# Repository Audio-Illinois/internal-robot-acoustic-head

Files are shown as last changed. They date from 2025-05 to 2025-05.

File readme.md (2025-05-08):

# Robotic Dummy Heads for Acoustic Data Collection

This repository contains open-source resources for building and using **robot dummy heads**, developed to collect high-quality data for the study of audio and acoustic processing algorithms. These heads are designed to mimic human acoustic properties while being mountable on robotic platforms, supporting realistic audio data capture even in environments with source motion.

<div style="text-align:center">
Banner image showing 3D printed heads assembled in a row and disassembled in a suitcase. University/sponsor affilidations are shown at the bottom
</div>

## Overview
In tasks like sound localization, speech enhancement, or multi-microphone array processing, capturing realistic human-like audio is critical. Our dummy heads are designed to:

- Accurately model human head-related transfer functions (HRTFs)
- Provide interchangeable components for various research needs
- Integrate naturally with robotic platforms (e.g. our quiet turntable)

Our quiet turntable is designed to:
- Be inaudible in the far-field (>1.0 m), enabling recordings with source motion that are not possible with conventional, noisy robots
- Accurately repeat prior movements, enabling the use of objective performance metrics

Overall, these tools enable robust, reproducible audio data collection under controlled and in-the-wild conditions.

## Repository Structure

The project is modular, with each core component in its own subdirectory:

```
robot-dummy-head/
├── head-shell/ # 3D models and manufacturing specs for the head structure
├── robot-mount/ # The quiet turntable robot: 3D models, electronics, and code
└── auto-audio/ # Scripts for automated spatially-stationary and dynamic recordings with the head+robot
```

Further, detailed information can be found in each directory. `auto-audio` presumes that `head-shell` and `robot-mount` have been viewed and the instructions within followed, yielding the fully-assembled robotic head.

## Getting Started

Each subdirectory contains a README with build instructions, parts lists, and diagrams. To get started quickly:

1. Clone this repo
2. Review the [`head-shell`](./head-shell) to purchase and assemble the parts of the dummy head
3. Follow [`robot-mount`](./robot-mount) to purchase and assemble the parts of the robot turntable
4. Use [`auto-audio`](./auto-audio) to perform automatic audio recordings using the head + robot

## Applications

- Binaural spatial audio
- Objective evaluation of audio and acoustic processing algorithms
- Dataset collection for speech source separation and enhancement
- Dataset collection for sound source localization

## Citation

If you use this resource in your research, please cite the following. Various acousitic measurements validating the acoustic realism of the dummy head or quietness and repeatability of the robot are provided in the paper as well.

```
@misc{lu2025,
      title={Accelerating Audio Research with Robotic Dummy Heads}, 
      author={Austin Lu and Kanad Sarkar and Yongjie Zhuang and Leo Lin and Ryan M Corey and Andrew C Singer},
      year={2025},
      eprint={2505.04548},
      archivePrefix={arXiv},
      primaryClass={eess.AS},
      url={https://arxiv.org/abs/2505.04548}, 
}
```

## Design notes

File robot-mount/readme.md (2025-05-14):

# Quiet Rotating Platform

This turntable locks onto the 3D printed head and rotates it quietly, enabling audio experiments with _repeatable_ source motion.

## ⚙ 1. Sourcing the parts

#### 🖨 3D Print Files

All printable components are provided as `.stl` files in the [`solids/`](./solids) directory:

| Links | Description |
| --- | --- |
| [Base Platform](./solids/base.stl) <br/> + [Motor Case](./solids/motorcase.stl) | The main stationary part of the turntable that encases the motor and homing induction sensor |
| [Grabber](./solids/grabber.stl) <br/> + [Plate](./solids/plate.stl) | The payload portion of the turntable that friction-fits with a dummy head and is rotated by the motor |

#### 🧾 PCB Fabrication Files

All files required for manufacturing the PCB can be found in [`gerber.zip`](./gerber.zip). This can be uploaded to a PCB manufacturer such as [PCBWay](https://www.pcbway.com/) and fabricated with low turnaround time and cost. Tutorials on using PCBWay are available on YouTube.

#### 🔩 Purchased Parts

The following parts need to be soldered to the PCB.

| Part | Qty | Designation on Schematic | Link |
| --- | --- | --- | --- |
| Arduino Nano | 1 | None | [arduino](https://store.arduino.cc/products/arduino-nano) |
| TMC 2208 motor driver chip | 1 | None | [digikey](https://www.digikey.com/short/j84mhvfm)|
| Terminal Block for stepper motor | 1 | J2 (Screw_Terminal for motor) | [digikey](https://www.digikey.com/en/products/detail/phoenix-contact/1715747/260633) |
| Barrel Jack for power | 1 | J1 (Barrel_Jack) | [digikey](https://www.digikey.com/en/products/detail/same-sky-formerly-cui-devices/PJ-002A/96962) |
| PinSocket headers for Arduino Nano | 2 | J3, J5 | [digikey](https://www.digikey.com/en/products/detail/sullins-connector-solutions/PPTC151LFBN-RC/810153) |
| PinSocket headers for TMC 2208 driver chip | 2 | J4, J6 | [digikey](https://www.digikey.com/en/products/detail/w%C3%BCrth-elektronik/61300811821/17737805) |
| Induction sensor terminal block | 1 | J7 | [digikey](https://www.digikey.com/en/products/detail/phoenix-contact/1715734/260632) |
| Adafruit adjustable power supply  (Run it at 18 Volts) | 1 | None | [digikey](https://www.digikey.com/short/31r0mw15)  |
| Induction sensor | 1 | None | [amazon](https://www.amazon.com/Taiss-NO%EF%BC%88Normally-LJ12A3-4-Z-inductive-Proximity/dp/B073XD44CW) |

The following components are used in/on the 3D printed parts.

| Part | Qty | Link |
| --- | --- | --- |
| Small-size Stepper Motor | 1 | [digikey](https://www.digikey.com/en/products/detail/adafruit-industries-llc/324/5022791)|
| Flanged ball bearing | 1 | [mcmaster](https://www.mcmaster.com/57155K573/) |
| M3x20mm screws | 5 | [mcmaster](https://www.mcmaster.com/91292A123/) |
| M3x8mm screws | 20 | [mcmaster](https://www.mcmaster.com/91292A112/) |
| Variable power supply* | 1 | [digikey](https://www.digikey.com/en/products/detail/adafruit-industries-llc/5130/15277535) |

*We set the voltage to 20V.

## 🔧 2. Assembly Instructions

Follow the designators on this PCB to solder the parts above. Alternatively, consult the [schematic](./imgs/pcb_v2_schematic.png)

<div style="text-align:center">
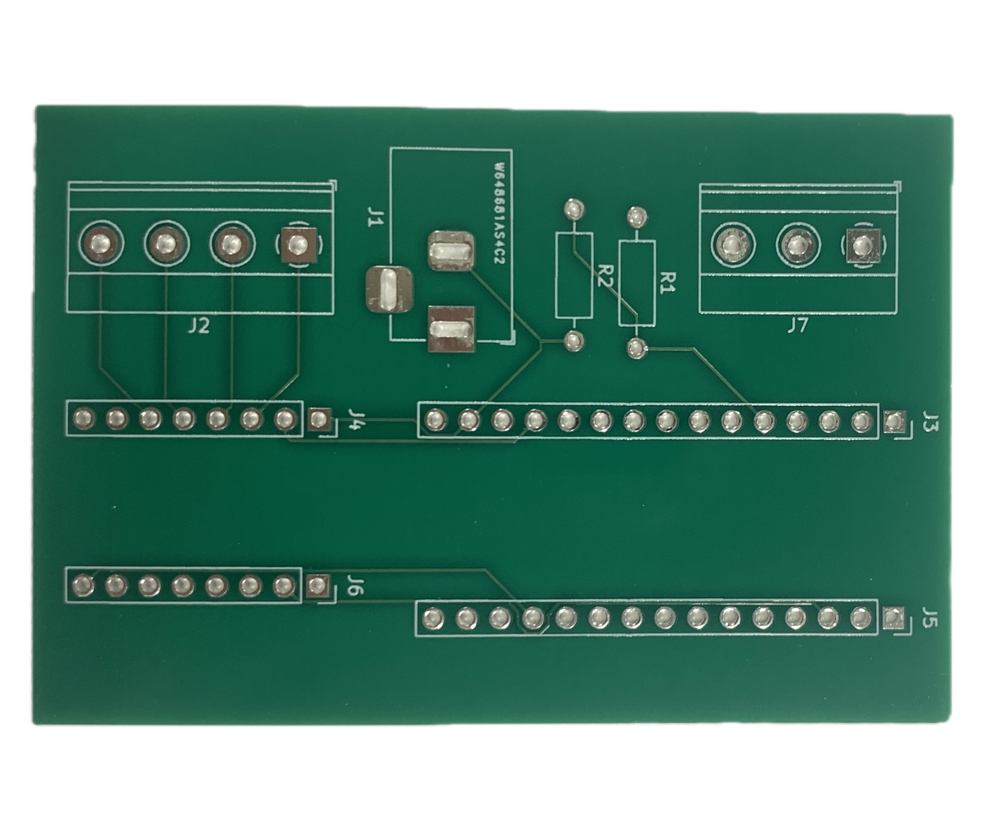
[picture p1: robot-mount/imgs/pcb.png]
Bare PCB

</div>

Final assembled PCB:

<div style="text-align:center">
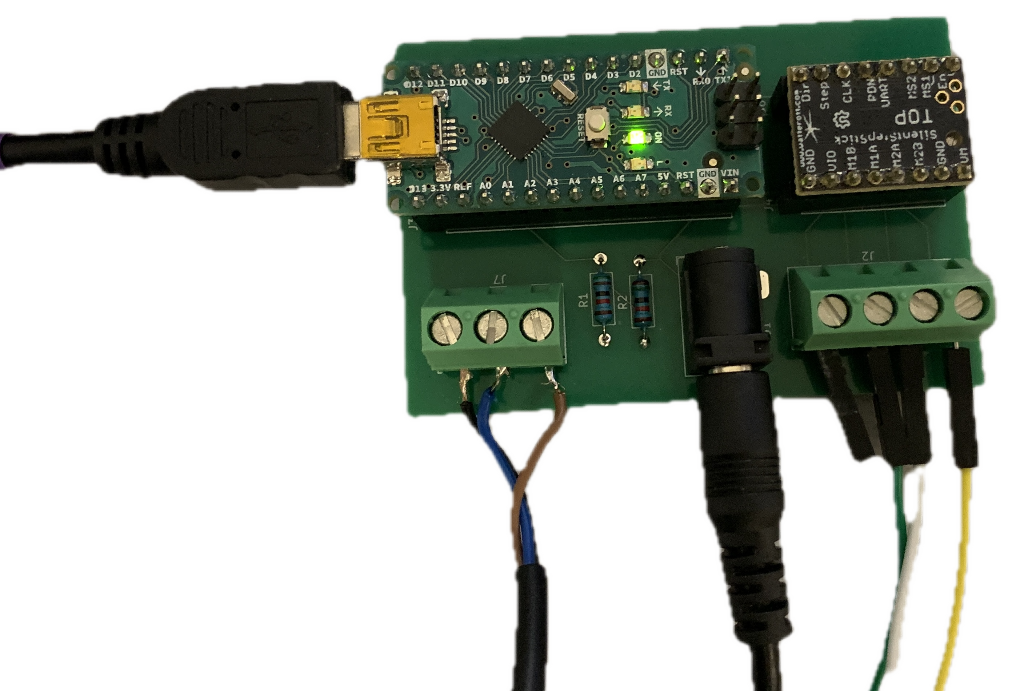
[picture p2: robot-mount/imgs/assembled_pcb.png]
Final Assembled PCB

</div>

The PCB can be connected to the motor as follows:
<div style="text-align:center">
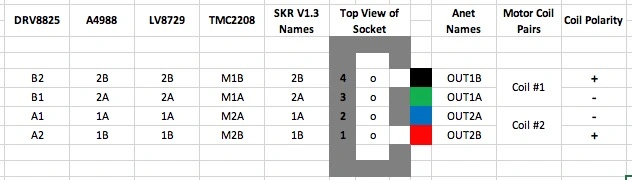
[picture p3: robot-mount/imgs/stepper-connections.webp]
Table of how to connect the motor to the driver

</div>

Follow [this](https://github.com/teemuatlut/TMC2208Stepper?tab=readme-ov-file) github tutorial to solder a UART bridge on the TMC motor driver.

Final assembled robot with dummy head:

<div style="text-align:center">
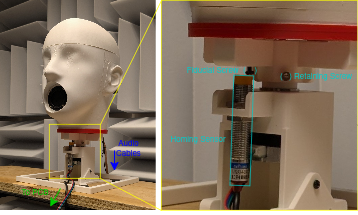
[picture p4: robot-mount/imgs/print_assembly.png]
Annotated photos of the dummy head atop the turntable. PCB excluded.

</div>

## 💾 3. Software

#### 1. Setup host PC

Clone the repository
```bash
git clone https://github.com/Audio-Illinois/robot-acoustic-head.git
cd robot-acoustic-head/robot-mount
```
Onto a PC with either ALSA (Linux) or ASIO (Windows) audio drivers. Preferably, have Python 3.8.10 installed.

Install the necessary libraries
```bash
python3 -m pip install -r ./requirements.txt
```

#### 2. Flash Arduino

Install [`arduino-cli`](https://docs.arduino.cc/arduino-cli/installation/) for convenient Arduino flashing. Then, run:
```bash
arduino-cli lib install tmc2208stepper # install needed library package

cd scripts
python3 ./upload.py -P $PORT
```
> 💡 On an Ubuntu machine, you likely should set `PORT=/dev/ttyUSB0`. On Windows, try `PORT=COM4`.

Errors are expected when first calling this script - just follow the suggestions provided.

This is optional and you can instead use the [Arduino IDE](https://www.arduino.cc/en/software/), which will also make identifying the relevant serial port easier.

In either case, ensure that the [TMC2208Stepper](https://docs.arduino.cc/libraries/tmc2208stepper/) library is installed via Package Manager.

#### 3. Control the robot through console commands

Run 
```bash
python3 ./teleop.py $PORT
```

Example commands are `home`, which can be used to check that the homing induction sensor is wired properly, and `move <degrees>`/`move <degrees> <revs/s>` which is used to check that the motor calibration is correct. 

> 💡 It is advised to clamp the robot turntable onto a desk or other heavy platform.

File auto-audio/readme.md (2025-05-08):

# Automated Experiments with the Robot Dummy Head

Presuming you have both the dummy head in [`../head-shell/`](../head-shell/) and robot turntable in [`../robot-mount/`](../robot-mount/) set up an assembled properly, with teleop working for the latter, then you can run some basic automated experments using the scripts in this folder.

## 1. Setup

Connect the host PC to:
1. The robot PCB, via USB serial
2. Any audio interface

Ensure that the audio interface can be identified via Python. Note that the `sounddevice` library uses `PortAudio` to this end.

```python
import sounddevice as sd
sd.query_devices()
```

> 💡 A common issue is your device being listed, but with 0 input or output channels. Check that no other application is using the audio interface, or on Ubuntu, run `pulseaudio -k` to reset system audio.

Check robot responsiveness by following the guide in [`../robot-mount/`](../robot-mount/). Keep an eye out for egregious latency between submitting a command and the robot performing that action, or for mismatch between the commanded motion extent and the observed movement.

> 💡 On an Ubuntu machine, you likely should set `PORT=/dev/ttyUSB0`. On Windows, try `PORT=COM4`.

## 2. Automatic HRTF or Directivity recordings

Run
```bash
python3 ./auto_still.py -p $PORT -r $path_to_wav_to_play -w $path_to_save_recordings_to
```
to have the dummy head rotated in a full 360 degrees, in increments of 45 degrees. At each position, audio at `$path_to_wav_to_play` is played from the mouth loudspeaker (or whichever loudspeakers are connected to the audio interface). At the same time, audio is recorded from both ears (or whichever mics are connected to the audio interface) to `$path_to_save_recordings_to`. Before recording, the dummy head will self-home.

To measure an HRTF, instead of the mouth loudspeaker, a studio monitor in the far-field could be used as the audio output.
```bash
python3 ./auto_still.py -p $PORT -r $path_to_wav_to_play -w $path_to_save_recordings_to -i 15
```

To mesaure directivity of the dummy head, record from a single microphone in the far-field.
```bash
python3 ./auto_still.py -p $PORT -r $path_to_wav_to_play -w $path_to_save_recordings_to -i 15 -c 1
```

For convenience, we provide a [clip of a reading of the Rainbow Passage](https://www.voxforge.org/home/audacity/the-rainbow-passage) at `./audio/rp-01.wav`. 

## 3. Recording a moving sound source

Run
```bash
python3 ./auto_move.py -p $PORT -r $path_to_wav_to_play -w $path_to_save_recordings_to
```
to have the dummy head rotate _while_ audio is played and recorded. Before recording, the dummy head will self-home.

> 💡 A possible issue is latency in the recorded audio. This can be remedied with a loopback audio channel and subsequent sample-wise synchronization in post-processing.

> 💡 The above scripts were tested on an host PC with Ubuntu 20.04 LTS, ALSA audio, and Python 3.8.10, connected to a [Behringer U-Phoria UMC202HD](https://www.behringer.com/product.html?modelCode=0805-AAR) audio interface.

> 💡 Due to the choice of a weak-as-possible stepper motor, any tangles in the dummy head cables will **not** cause the dummy head to fall, or the cables to be damaged.

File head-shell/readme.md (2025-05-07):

# 3D Printed Dummy Head

When equipped with microphones in the faux ear canals, this dummy head can record realistic binaural audio. Using a loudspeaker at the mouth position, it may also produce humanlike speech, with appropriate directivity.

The parts are interlocking so that the design is fully 3D printed. Small screws can be used for stronger assembly, but this is optional.

<div style="text-align:center">
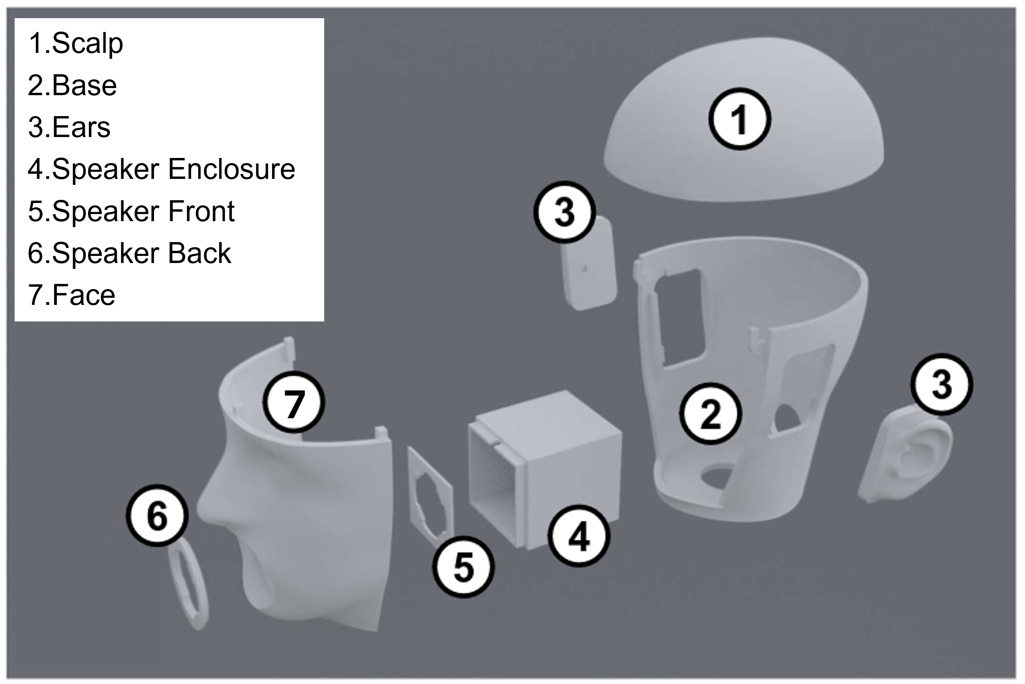
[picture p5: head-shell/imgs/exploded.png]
Exploded view of head parts

</div>

## Sourcing the Parts

#### 🖨 3D Print Files

All printable components are provided as `.stl` files in the [`solids/`](./solids) directory:

| Links | Features | Approx. Print Time* | Approx. Filament Usage** |
| --- | --- | --- | --- |
| [Left Ear](./solids/ear_left.stl) <br/> + [Right Ear](./solids/ear_right.stl) | Faux ear canals <br/> Realistic shape for binaural recordings | 3 hours (per) | 7 m (per) |
| [Base](./solids/main_base_repair.stl) <br/>+ [Face](./solids/main_face.stl) <br/>+ [Scalp](./solids/main_scalp_repair.stl) | Realistic proportions and ear-to-ear distance <br/> Port for microphone/loudspeaker cables | 18 hours (per) | 75±5 m (per)
| [Mouth Loudspeaker Enclosure](./solids/speaker_box.stl) <br/>+ [Front mounting plate](./solids/speaker_mount_front.stl) <br/>+ [Backplate](./solids/speaker_mount_back.stl) | Realistic talker directivity | 5 hours (total) | 25 m (total) |

*Based on a [Creality 3D Ender-5 Plus](https://www.creality.com/products/ender-5-plus-3d-printer) 3D Printer. The extra bed size of this printer is not actually necessary to print the head parts. We recommend using a [Bambu Lab X1 Carbon](https://us.store.bambulab.com/products/x1-carbon) for 3-4x faster print times.

**The full dummy head can be printed from a single [1 kg spool of 1.75mm PLA filament](https://www.hatchbox3d.com/collections/pla-1-75mm).

To print the parts:

1. **Open the `.stl` files** using a slicer program like [Bambu Studio](https://bambulab.com/en/software/studio) (we use this), [PrusaSlicer](https://www.prusa3d.com/prusaslicer/), or [Cura](https://ultimaker.com/software/ultimaker-cura).
   - Move the models so they don't intersect/overlap
   - Use the Auto-Orient tool to snap the models to the print bed, in an orientation that will reduce print time and support material usage
2. **Configure printer settings**.
   - Material: PLA (recommended)
   - Layer height: 0.2 mm (default)
   - Infill: 15% (default)
   - Supports: Type=normal(auto), Style=Snug
3. **Slice and export** the G-code.
   - The estimated print times and filament usage should roughly align with the above listed
4. **Print** the part using your 3D printer.

Need help getting started? Check out:
- [Beginner’s Guide to 3D Printing by All3DP](https://all3dp.com/2/how-to-3d-print-beginners-guide/)
- [Bambu Lab's Quick Start Guide](https://wiki.bambulab.com/en/x1/quick-start-guide)

#### 🔩 Purchased Parts
| Links | Qty | Features |
| --- | --- | --- |
| [Countryman B3 Omnidirectional Lavalier](https://countryman.com/product/b3-omnidirectional-lavalier/) | 2 | Omnidirectional <br/> Wired, for synchronous multi-channel audio <br/> Friction-fit between microphone cap and ear parts. |
| [Tectonic TEBM34C10-4 BMR 2" Full-Range Speaker](https://www.parts-express.com/Tectonic-TEBM35C10-4-BMR-2-Full-Range-Speaker-4-Ohm-297-216) | 1 | Human-like directivity ([compared to a studio monitor](https://pubs.aip.org/asa/jasa/article/148/4/2371/995223)) <br/> Flat frequency response |
| [Fosi Audio TB10D Amplifier](https://fosiaudio.com/pages/2-channel-amplifier-tb10d) | 1 | |
| [M2x12mm screws](https://www.mcmaster.com/products/screws/thread-size~m2/length~12-mm/) for fastening the loudspeaker | 4 | |
| [M2 nuts](https://www.mcmaster.com/products/nuts/thread-size~m2/) for fastening the loudspeaker | 4 | |
| [M2x6mm screws](https://www.mcmaster.com/products/screws/thread-size~m2/length~6-mm/) for fastening the ears/scalp (optional) | 4 | |

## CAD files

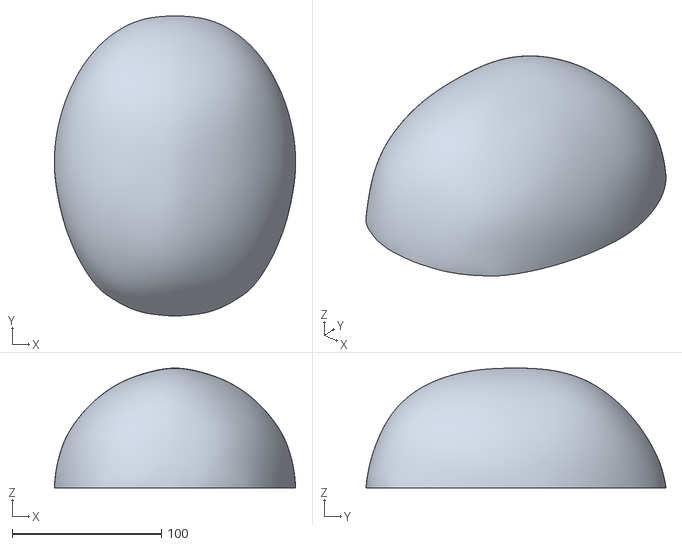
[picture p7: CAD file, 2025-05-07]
head-shell/solids/main_scalp_repair.stl
161.8 x 201.2 x 80.4

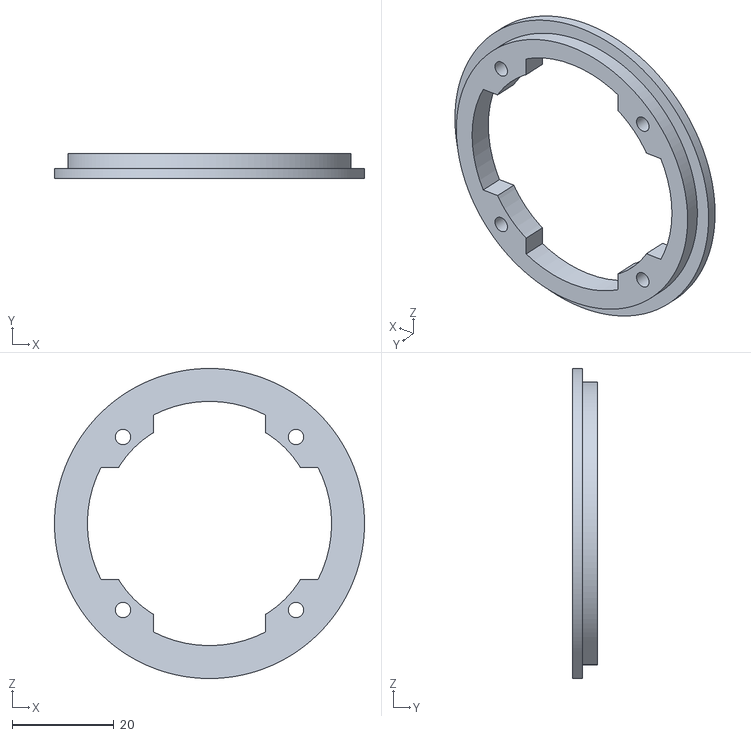
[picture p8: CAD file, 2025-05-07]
head-shell/solids/speaker_mount_front.stl
60.9 x 5.00 x 60.9

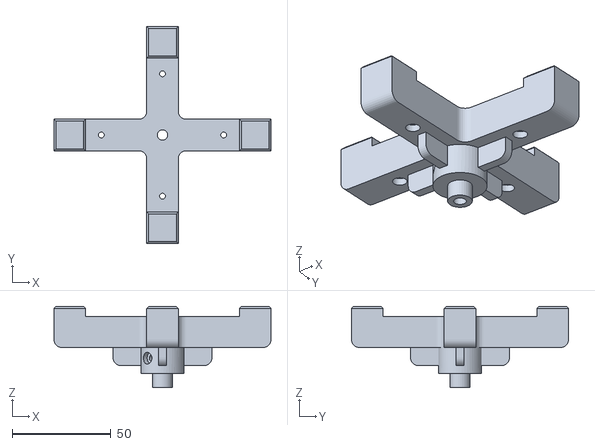
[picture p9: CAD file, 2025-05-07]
robot-mount/solids/grabber.stl
110.0 x 110.0 x 41.1

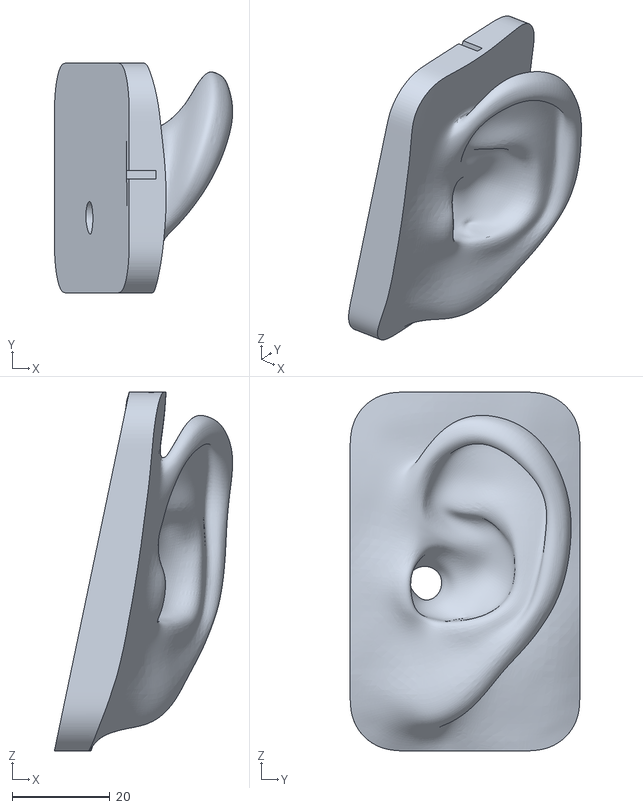
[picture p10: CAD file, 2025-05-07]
head-shell/solids/ear_left.stl
36.5 x 47.0 x 73.5

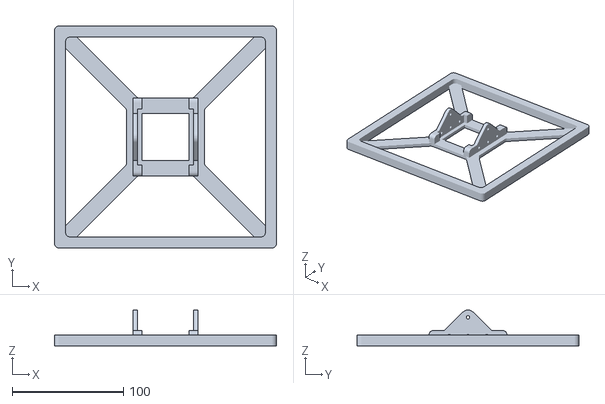
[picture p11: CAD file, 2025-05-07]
robot-mount/solids/base.stl
200.0 x 200.0 x 32.4

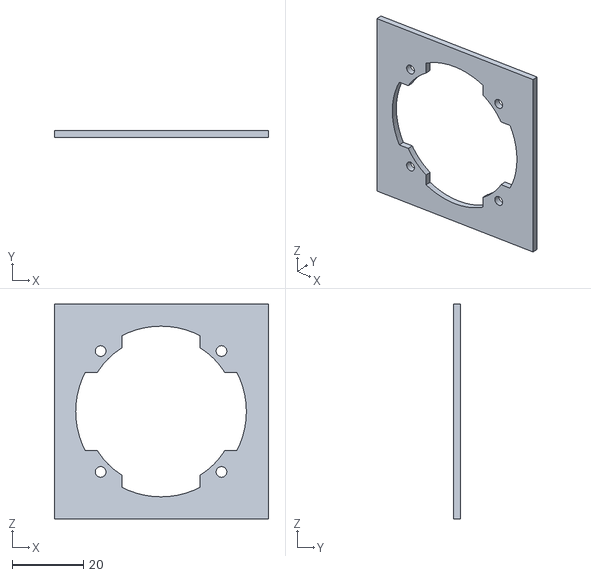
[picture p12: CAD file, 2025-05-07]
head-shell/solids/speaker_mount_back.stl
60.2 x 2.00 x 60.4

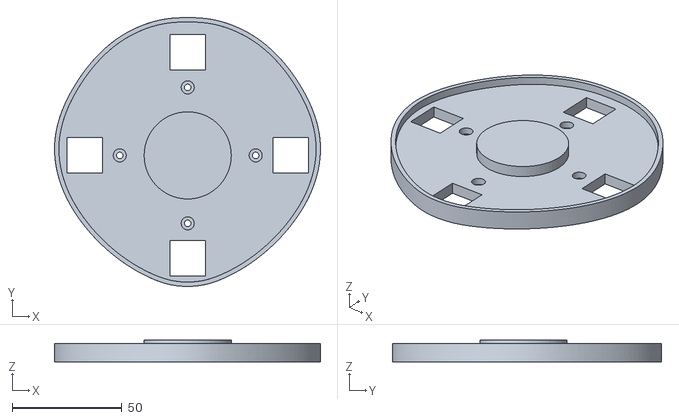
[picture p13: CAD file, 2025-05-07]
robot-mount/solids/plate.stl
121.3 x 122.6 x 10.0

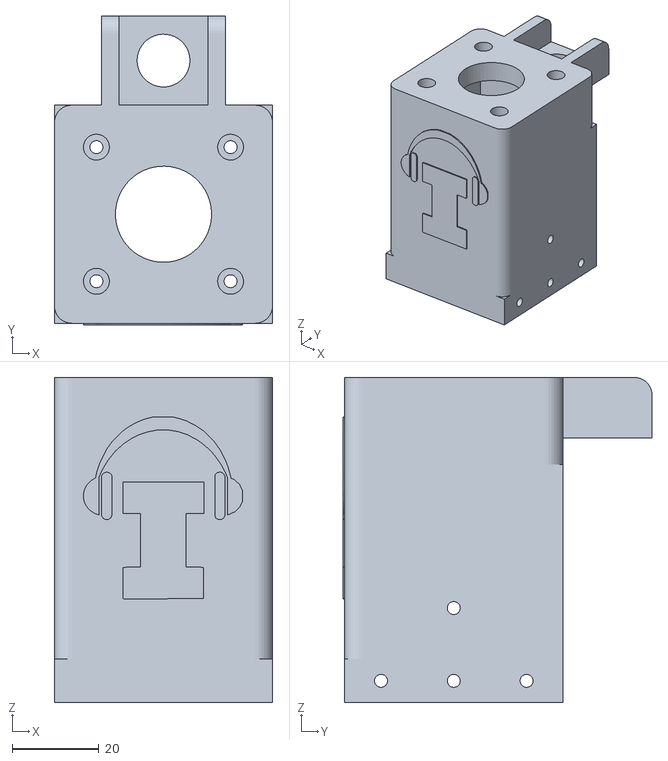
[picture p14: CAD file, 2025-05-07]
robot-mount/solids/motorcase.stl
50.4 x 71.4 x 75.1

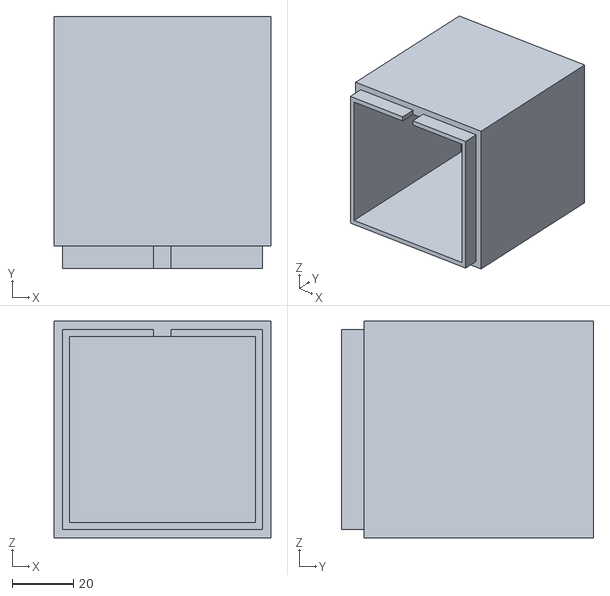
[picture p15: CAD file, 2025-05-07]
head-shell/solids/speaker_box.stl
70.9 x 82.5 x 70.9

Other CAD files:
head-shell/solids/ear_right.stl

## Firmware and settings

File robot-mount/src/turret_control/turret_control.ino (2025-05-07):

// Pin Definitions
#define STEP_PIN            10
#define RX_PIN              2
#define TX_PIN              3
#define EN_PIN              12
#define SENSOR_PIN          A1 // Inductive sensor

// Motor Constants
#define CURRENT             750 // 726
#define USTEPS_PER_STEP     4
#define STEPS_PER_REV       200
#define USTEPS_PER_REV      STEPS_PER_REV * USTEPS_PER_STEP
#define HOMING_ADJUSTMENT   12 // usteps, extra movement to center on homing sensor
#define HOMING_PAUSE        1000 // milliseconds, small pause to help observe and adjust homing adjustment
#define HOMING_SPEED        0.01

// Communication Constants
#define PULSE_WIDTH         200 // microseconds
#define CMD_HOME            "home"
#define CMD_MOVE            "move"
#define RPS_QSCALE          1000

// Library Includes
#include <TMC2208Stepper.h>
#include <SoftwareSerial.h>

// Global Objects and Variables
SoftwareSerial motorSerial(RX_PIN, TX_PIN);
TMC2208Stepper driver = TMC2208Stepper(&motorSerial);

// Check if home sensor is detecting something
bool isHomed() {
  return digitalRead(SENSOR_PIN) == HIGH;
}

// Send one PWM pulse
void _step() {
  digitalWrite(STEP_PIN, HIGH);
  delayMicroseconds(PULSE_WIDTH);
  digitalWrite(STEP_PIN, LOW);
}

// Base Utility: Run motor for a certain extent at a speed (rev/s)
void _rotate(int usteps, float rps, bool (*stop_cond)()=[]() {return 0;} ) {
  float abs_usteps = usteps;
  float usecPerStep = 1000000.0 / (rps * USTEPS_PER_REV);

  if (usteps < 0) {
      abs_usteps = -abs_usteps; // if negative, make positive
      driver.shaft(1); // Reverse Direction 
  }

  // Do nothing if movement might be out of bounds
  if (usecPerStep < PULSE_WIDTH) { return; }

  for (unsigned long i = 0; i < abs_usteps; i++) {
    _step();
    delayMicroseconds(usecPerStep);
    if (stop_cond()) {
      break;
    }
  }

  if (usteps < 0) { driver.shaft(0); } // Un-Reverse
}


// Basically a wrapper of _rotate with an exit flag
void Move(int usteps, float rps, int delay_ms=0) {
  delay(delay_ms);
  _rotate(usteps, rps);
  Serial.println(CMD_MOVE);
}


// Run calibration sequence until sensor is triggered
void Home() {
  if (!isHomed()) { // Avoid unecesmove adjustment (will un-home payload) if already homed
    _rotate(USTEPS_PER_REV, HOMING_SPEED, isHomed);
    delay(HOMING_PAUSE);
    Move(HOMING_ADJUSTMENT, HOMING_SPEED); // Rotate for slightly longer to properly center
  }
  Serial.println(CMD_HOME);
}


// PC-Arduino Communication
String ReadCommand() {
  String cmd = Serial.readStringUntil('\n');
  cmd.trim();
  return cmd;
}


int ReadValue() { return ReadCommand().toInt(); }


// Arduino Main Functions
void setup() {
  Serial.begin(115200);
  motorSerial.begin(115200);

  pinMode(STEP_PIN, OUTPUT);
  pinMode(EN_PIN, OUTPUT);
  pinMode(SENSOR_PIN, INPUT);

  driver.pdn_disable(1);                // Use UART communication
  driver.I_scale_analog(0);             // Use digital current control
  driver.rms_current(CURRENT, 1.0);          // Set current
  driver.toff(5);                        // Enable driver (low time)
  driver.en_spreadCycle(0);             // Use stealthChop mode
  driver.pwm_autoscale(1);              // Enable voltage regulator
  driver.mstep_reg_select(1);
  driver.microsteps(USTEPS_PER_STEP);   // Set microstep resolution
  driver.TPWMTHRS((uint32_t)0);                   // Never automatically go from stealthChop to spreadCycle
  driver.TPOWERDOWN((uint32_t)2);

  driver.push(); // Apply settings
}

void loop() {
  if (Serial.available()) {
    String cmd = ReadCommand();

    if (cmd==CMD_HOME) {
      Home();
    } else if (cmd==CMD_MOVE) {
      float rps = ReadValue() / (float)RPS_QSCALE;
      int usteps = ReadValue();
      int delay_ms = ReadValue();
      Move(usteps, rps, delay_ms);
    } else {
      delay(200);
      Serial.println(cmd);
    }
  }
}

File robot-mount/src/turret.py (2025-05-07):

import serial
import time
import numpy as np
import sys, time

# Constants
DEFAULT_PORT = 'COM4'
DEFAULT_BAUDRATE = 115200
DEFAULT_TIMEOUT = 0.1
DEFAULT_STARTUP_DELAY = 2
USTEPS_PER_STEP = 4
STEPS_PER_REV = 200
OFFSET_HOME = 9
CMD_HOME = 'home'
CMD_MOVE = 'move'
RPS_QSCALE = 1000
DEFAULT_SPEED = 0.1
INT_MAX = 2**15 # 16 bit Arduino, unsigned

class Turret:
    def __init__(
            self,
            port:str=DEFAULT_PORT,
            baudrate:int=DEFAULT_BAUDRATE,
            timeout:float=DEFAULT_TIMEOUT,
            startup_delay:float=DEFAULT_STARTUP_DELAY,
        ):
        self.arduino = serial.Serial(port=port, baudrate=baudrate, timeout=timeout)
        time.sleep(startup_delay) # Allow Arduino to initialize
        print ('Setup complete.')

    def GracefulExit(self):
        self.Home()        
        sys.exit(0)

    def Command(self, command:str, values=[], scales=None, block=True, on_start=None, on_end=None):
        '''
        Send a `command` string with a list of `values` (optional, int) along the serial port to the Arduino
        '''
        if scales is None: scales = np.ones(len(values), dtype=int)

        scaled = np.array([value*scale for value, scale in zip(values, scales)])
        assert np.allclose(scaled, scaled.astype(int)), f"{scaled}"
        assert np.all(abs(scaled) < INT_MAX)

        quantized = [str(int(value)) for value in scaled]
        packet = '\n'.join([command, *quantized, ''])

        log_packet = packet.replace("\n", " ")
        print(f'Command: {log_packet:<30}', end='' if on_start is None else '\n', flush=True)
        self.arduino.write(packet.encode())
        self.arduino.flush()

        if on_start is not None:
            on_start()
        print('\tStatus: ', end='', flush=True)

        if block:
            while True:
                from_arduino = self.arduino.readline().decode().strip()
                if from_arduino == command: # successful echo
                    if on_end is not None: on_end()
                    print ('Done')
                    break

    def Home(self, on_start=None, on_end=None):
        self.Command(CMD_HOME, on_start=on_start, on_end=on_end)
        self.Move(deg=-OFFSET_HOME,rps=DEFAULT_SPEED)
        self.Command(CMD_HOME, on_start=on_start, on_end=on_end)

    def Move(self, deg:int, rps:float=DEFAULT_SPEED, delay_ms:int=0, on_start=None, on_end=None):
        usteps = deg * USTEPS_PER_STEP * STEPS_PER_REV / 360.0
        if not np.isclose(usteps, int(usteps)):
            print (f'WARNING: {usteps:.3f} not int! Casted to {int(usteps)}')
            usteps = int(usteps)
        self.Command(
            CMD_MOVE,
            values=[rps, usteps, delay_ms],
            scales=[RPS_QSCALE, 1, 1],
            on_start=on_start,
            on_end=on_end
        )

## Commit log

2025-05-07 Add all
    [base.stl, ear_left.stl, ear_right.stl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]
2025-05-07 Add assembly image of 3D print parts
2025-05-14 Add arduino-cli tip
